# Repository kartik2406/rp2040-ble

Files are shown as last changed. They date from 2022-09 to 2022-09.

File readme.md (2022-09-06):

# RP2040 BLE

A PCB that uses RP2040 MCU and HM-BT4502 BLE passthrough module.
This enables the RP2040 to communicated with other devices using Bluetooth.
The bluetooth module is connected via UART(0)

## 3D
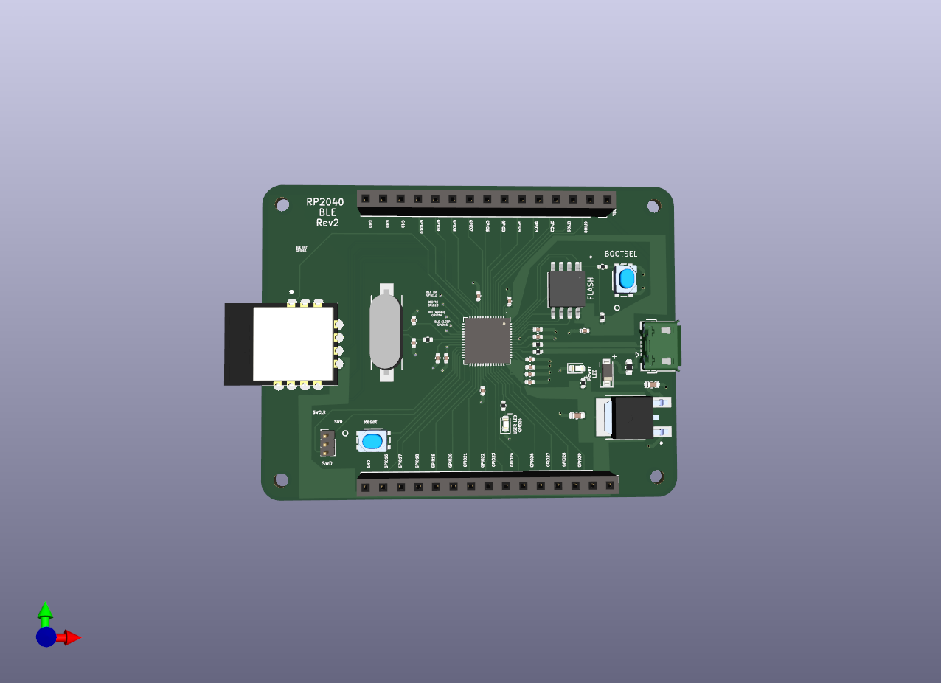
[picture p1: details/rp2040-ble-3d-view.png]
PCB 3D view


## PCB front layer
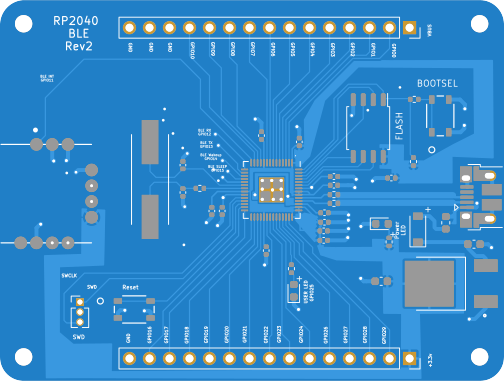
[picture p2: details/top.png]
PCB Front


## PCB back layer
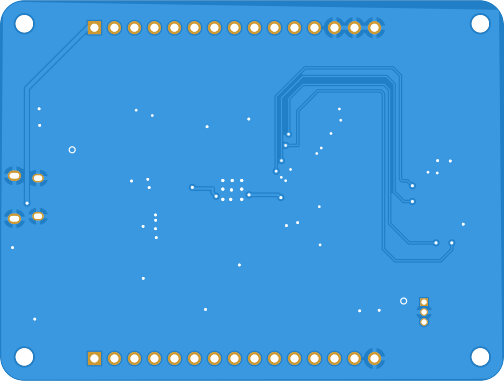
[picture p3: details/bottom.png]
PCB Back


## Generating board images
I used the gerber viewer on [PCBWay](https://www.pcbway.com/project/OnlineGerberViewer.html),
Downloaded the SVG renders from it, then converted the top and bottom SVGs to PNGs

## Helpful tutorials
- [The RP2040 hardware design guide, its in depth and cover things nicely](https://datasheets.raspberrypi.com/rp2040/hardware-design-with-rp2040.pdf)
- [An Intro to KiCad – Part 1: How PCBs Are Made](https://www.youtube.com/watch?v=vaCVh2SAZY4&list=PLEBQazB0HUyR24ckSZ5u05TZHV9khgA1O&ab_channel=Digi-Key)
- [Hardware Design with the RP2040: Custom PCB Based on the Raspberry Pi Pico](https://www.youtube.com/watch?v=kcwvuwetgEQ&ab_channel=Digi-Key)
- [Raspberry Pi RP2040 Hardware Design](https://www.youtube.com/watch?v=X00Cm5LMNQk&ab_channel=Phil%E2%80%99sLab)
- [KiCad STM32 + USB + Buck Converter PCB Design](https://www.youtube.com/watch?v=C7-8nUU6e3E&ab_channel=Phil%E2%80%99sLab)
- [KiCad 6 STM32 PCB Design Full Tutorial ](https://www.youtube.com/watch?v=aVUqaB0IMh4&ab_channel=Phil%E2%80%99sLab)
- [Designing a PCB for the RP2040 Microcontroller](https://www.teachmemicro.com/designing-a-pcb-for-the-rp2040-microcontroller/)
## Credits
- Most of the tutorial videos are from [Shawn Hymel](https://www.youtube.com/c/ShawnHymel), [Phil’s Lab](https://www.youtube.com/c/PhilS94).
They have amazing content do check them out.
- [Reddit PCB review thread](https://www.reddit.com/r/PrintedCircuitBoard/comments/wz8so7/pcb_review_rp2040_based_ble_board/),
thank you [Worldly-Protection-8](https://www.reddit.com/user/Worldly-Protection-8/), [DNosnibor](https://www.reddit.com/user/DNosnibor/) for the valuable review and feedback.

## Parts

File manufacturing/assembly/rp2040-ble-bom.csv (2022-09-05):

Source: | D:\electronic-schematics\rp2040-ble\rp2040-ble.kicad_sch
Date: | 04-09-2022 9.00.25 PM
Tool: | Eeschema (6.0.6)
Generator: | C:\Program Files\KiCad\6.0\bin\scripting\plugins/bom_csv_grouped_by_value_with_fp.py
Component Count: | 42
Ref | Qnty | Value | Cmp name | Footprint | Description | Vendor | Robu ID
C1, C2, C3, C4, C6, C7, C9, C11, C12, C14, | 10 | 100n | C_Small | Capacitor_SMD:C_0402_1005Metric | Unpolarized capacitor, small symbol | CL05B104KO5NNNC
C5, C8, | 2 | 1u | C_Small | Capacitor_SMD:C_0402_1005Metric | Unpolarized capacitor, small symbol | CL05A105KA5NQNC
C10, C13, | 2 | 27p | C_Small | Capacitor_SMD:C_0402_1005Metric | Unpolarized capacitor, small symbol | CL05C270JB5NNNC
C15, C16, | 2 | 10u | C_Small | Capacitor_SMD:C_0603_1608Metric | Unpolarized capacitor, small symbol | CL10A106KP8NNNC
D1, | 1 | BLUE | LED_Small | LED_SMD:LED_0603_1608Metric | Light emitting diode, small symbol | 150060BS75000
D2, | 1 | GREEN | LED_Small | LED_SMD:LED_0603_1608Metric | Light emitting diode, small symbol | 150060VS75000
D3, | 1 | B5819W | D_Schottky_Small | Diode_SMD:D_SOD-123 | Schottky diode, small symbol | B5819W
F1, | 1 | 100mA | Polyfuse_Small | Fuse:Fuse_0603_1608Metric | Resettable fuse, polymeric positive temperature coefficient, small symbol | 0603L004YR
J1, J2, | 2 | Conn_01x15 | Conn_01x15 | Connector_PinSocket_2.54mm:PinSocket_1x15_P2.54mm_Vertical | Generic connector, single row, 01x15, script generated (kicad-library-utils/schlib/autogen/connector/)
J3, | 1 | USB_B_Micro | USB_B_Micro | Connector_USB:USB_Micro-B_Amphenol_10103594-0001LF_Horizontal | USB Micro Type B connector | 10103594-0001LF
J4, | 1 | Conn_01x03 | Conn_01x03 | Connector_PinHeader_1.27mm:PinHeader_1x03_P1.27mm_Vertical | Generic connector, single row, 01x03, script generated (kicad-library-utils/schlib/autogen/connector/)
R1, R2, | 2 | 27.4 | R_Small | Resistor_SMD:R_0402_1005Metric | Resistor, small symbol | RMCF0402FT27R4
R4, R5, R6, R7, | 4 | 1k | R_Small | Resistor_SMD:R_0402_1005Metric | Resistor, small symbol | RC0402FR-071KL
R8, | 1 | DNF | R_Small | Resistor_SMD:R_0402_1005Metric | Resistor, small symbol
SW1, SW2, | 2 | PTS810_SJK_250_SMTR_LFS | PTS810_SJK_250_SMTR_LFS | PTS810:PTS810 SJK 250 SMTR LFS |  | PTS810 SJK 250 SMTR LFS
U1, | 1 | RP2040 | RP2040 | Package_DFN_QFN:QFN-56-1EP_7x7mm_P0.4mm_EP3.2x3.2mm | A microcontroller by Raspberry Pi | SC0914(7) | 997534
U2, | 1 | W25Q128JVS | W25Q128JVS | Package_SO:SOIC-8_5.23x5.23mm_P1.27mm | 128Mb Serial Flash Memory, Standard/Dual/Quad SPI, SOIC-8 | W25Q128JVSIQ
U3, | 1 | HM-BT4502 | HM-BT4502 | Custom:MODULE_HM-BT4502 |  | 113990814 | 1195286
U4, | 1 | NCP1117DT33G | NCP1117DT33G | NCP1117DT33G:VREG_NCP1117DT33G |  | NCP1117DT33G
Y1, | 1 | ABLS-12.000MHZ-B4-T | ABLS-12.000MHZ-B4-T | ABLS-12:XTAL_ABLS-12.000MHZ-B4-T |  | ABLS-12.000MHZ-B4-T

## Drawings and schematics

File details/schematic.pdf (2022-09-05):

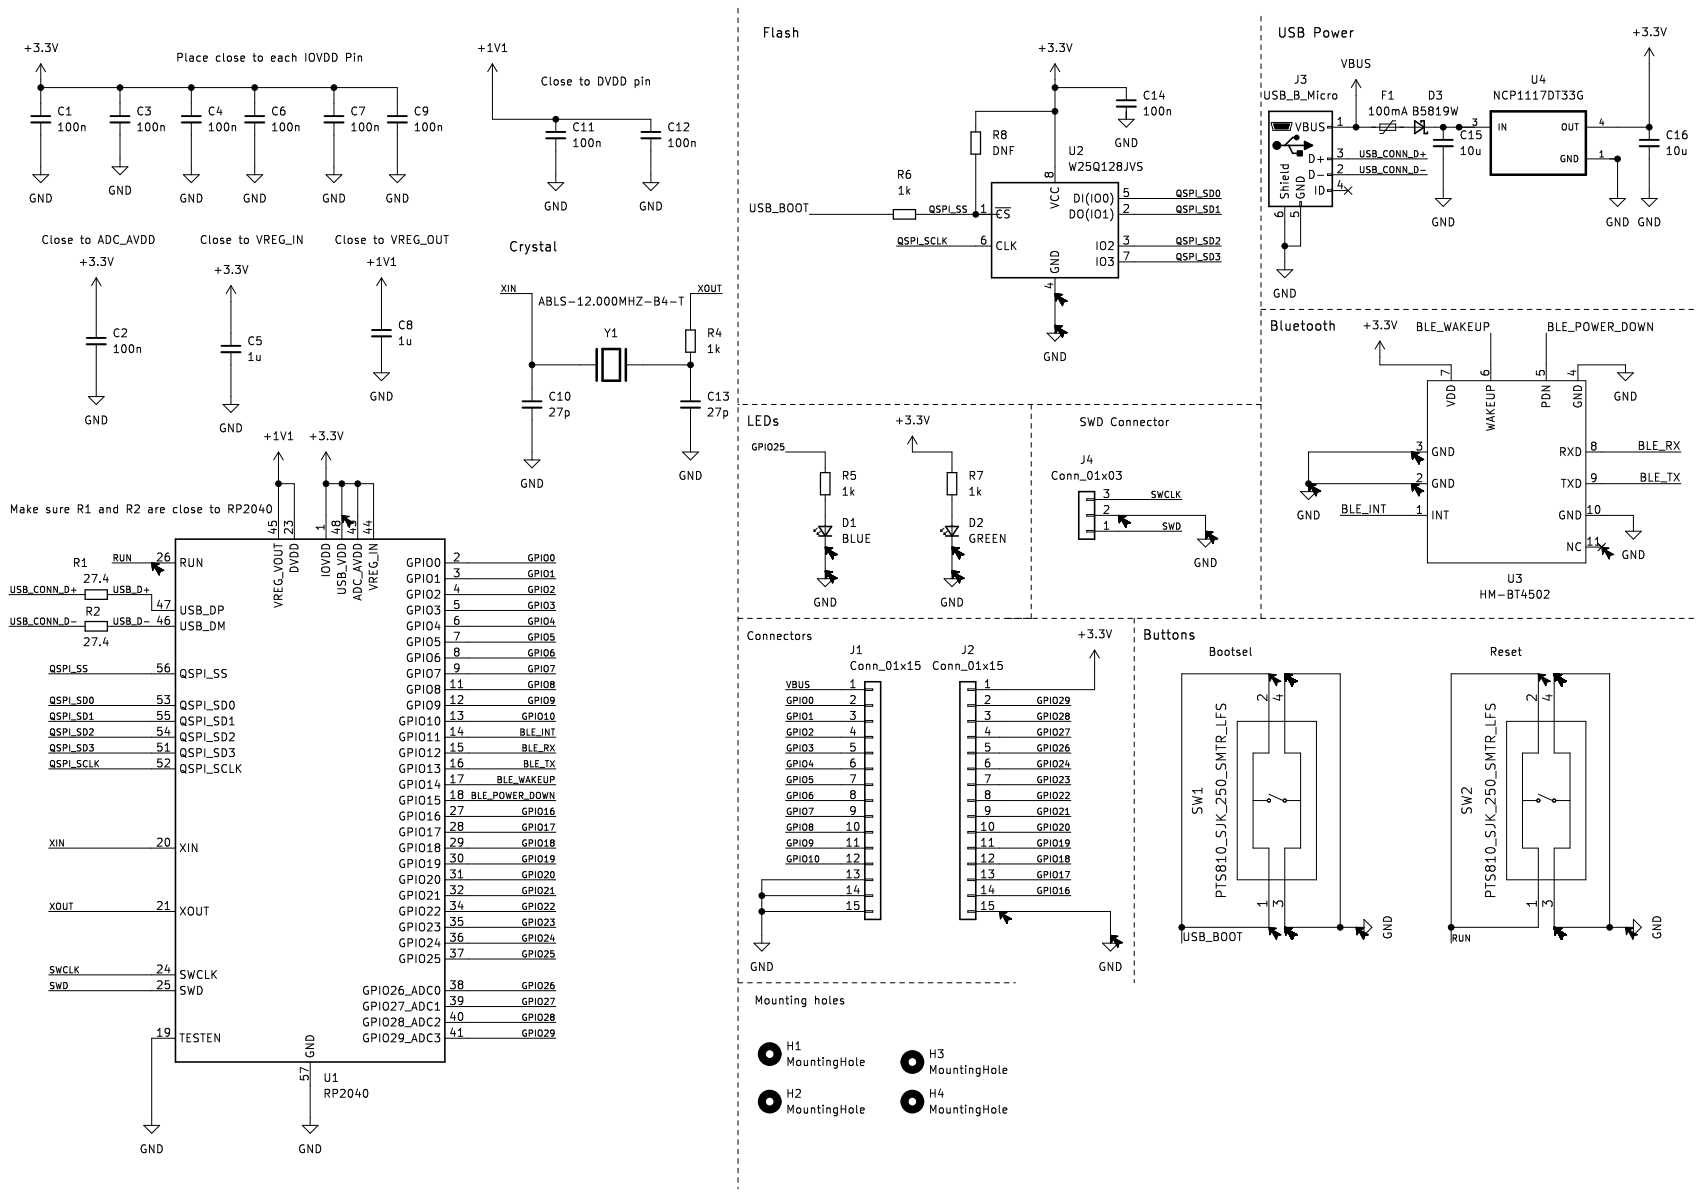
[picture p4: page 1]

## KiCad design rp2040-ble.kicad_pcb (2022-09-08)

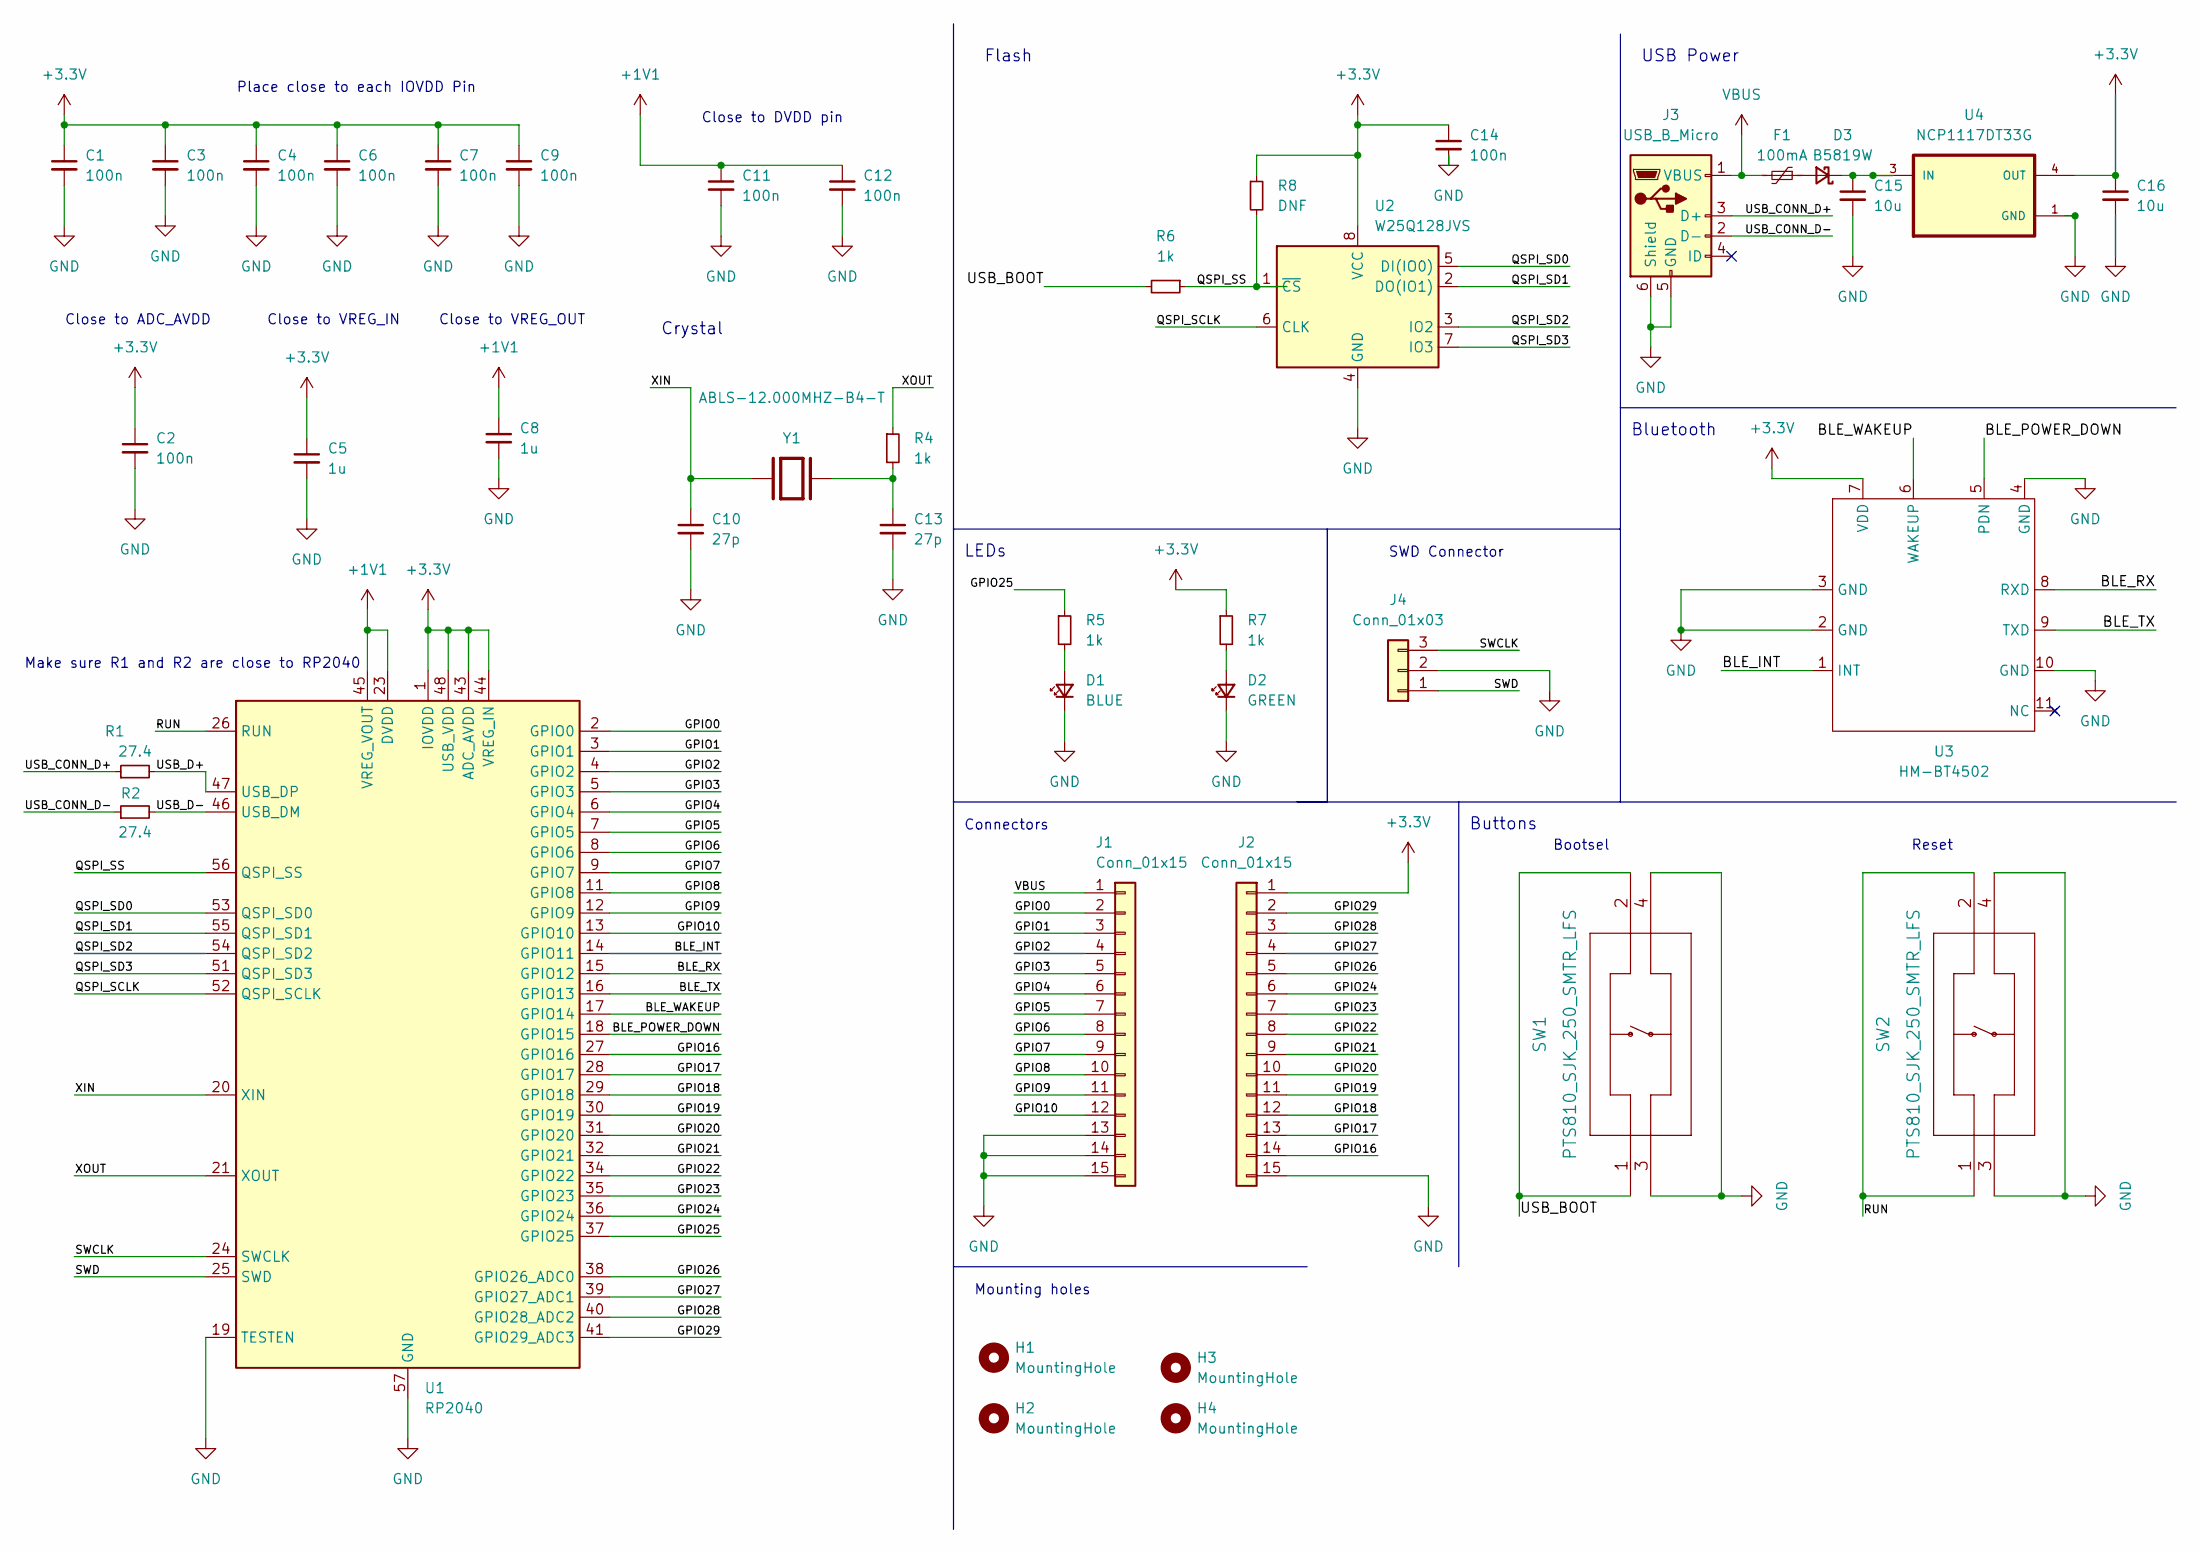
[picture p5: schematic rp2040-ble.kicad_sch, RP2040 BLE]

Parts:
C1, C2, C3, C4, C6, C7, C9, C11, C12, C14: 100n; C_0402_1005Metric
C5, C8: 1u; C_0402_1005Metric
C10, C13: 27p; C_0402_1005Metric
C15, C16: 10u; C_0603_1608Metric
D1: BLUE; LED_0603_1608Metric
D2: GREEN; LED_0603_1608Metric
D3: B5819W; D_SOD-123
F1: 100mA; Fuse_0603_1608Metric
H1, H2, H3, H4: MountingHole; MountingHole_2.2mm_M2
J1, J2: Conn_01x15; PinSocket_1x15_P2.54mm_Vertical
J3: USB_B_Micro; USB_Micro-B_Amphenol_10103594-0001LF_Horizontal
J4: Conn_01x03; PinHeader_1x03_P1.27mm_Vertical
R1, R2: 27.4; R_0402_1005Metric
R4, R5, R6, R7: 1k; R_0402_1005Metric
R8: DNF; R_0402_1005Metric
SW1, SW2: PTS810_SJK_250_SMTR_LFS; PTS810 SJK 250 SMTR LFS
U1: RP2040; QFN-56-1EP_7x7mm_P0.4mm_EP3.2x3.2mm
U2: W25Q128JVS; SOIC-8_5.23x5.23mm_P1.27mm
U3: HM-BT4502; MODULE_HM-BT4502
U4: NCP1117DT33G; VREG_NCP1117DT33G
Y1: ABLS-12.000MHZ-B4-T; XTAL_ABLS-12.000MHZ-B4-T; PARTREV 02.16.2021

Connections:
+1V1: C8.1, C11.1, C12.1, U1.23 (DVDD), U1.45 (VREG_VOUT), U1.50 (DVDD)
+3.3V: C1.1, C2.1, C3.1, C4.1, C5.1, C6.1, C7.1, C9.1, C14.1, C16.1, J2.1, R7.1, R8.1, U1.1 (IOVDD), U1.10 (IOVDD), U1.22 (IOVDD), U1.33 (IOVDD), U1.42 (IOVDD), U1.43 (ADC_AVDD), U1.44 (VREG_IN), U1.48 (USB_VDD), U1.49 (IOVDD), U2.8 (VCC), U3.7 (VDD), U4.4 (OUT)
/BLE_INT: U1.14 (GPIO11), U3.1 (INT)
/BLE_POWER_DOWN: U1.18 (GPIO15), U3.5 (PDN)
/BLE_RX: U1.15 (GPIO12), U3.8 (RXD)
/BLE_TX: U1.16 (GPIO13), U3.9 (TXD)
/BLE_WAKEUP: U1.17 (GPIO14), U3.6 (WAKEUP)
/GPIO0: J1.2, U1.2 (GPIO0)
/GPIO1: J1.3, U1.3 (GPIO1)
/GPIO2: J1.4, U1.4 (GPIO2)
/GPIO3: J1.5, U1.5 (GPIO3)
/GPIO4: J1.6, U1.6 (GPIO4)
/GPIO5: J1.7, U1.7 (GPIO5)
/GPIO6: J1.8, U1.8 (GPIO6)
/GPIO7: J1.9, U1.9 (GPIO7)
/GPIO8: J1.10, U1.11 (GPIO8)
/GPIO9: J1.11, U1.12 (GPIO9)
/GPIO10: J1.12, U1.13 (GPIO10)
/GPIO16: J2.14, U1.27 (GPIO16)
/GPIO17: J2.13, U1.28 (GPIO17)
/GPIO18: J2.12, U1.29 (GPIO18)
/GPIO19: J2.11, U1.30 (GPIO19)
/GPIO20: J2.10, U1.31 (GPIO20)
/GPIO21: J2.9, U1.32 (GPIO21)
/GPIO22: J2.8, U1.34 (GPIO22)
/GPIO23: J2.7, U1.35 (GPIO23)
/GPIO24: J2.6, U1.36 (GPIO24)
/GPIO25: R5.1, U1.37 (GPIO25)
/GPIO26: J2.5, U1.38 (GPIO26_ADC0)
/GPIO27: J2.4, U1.39 (GPIO27_ADC1)
/GPIO28: J2.3, U1.40 (GPIO28_ADC2)
/GPIO29: J2.2, U1.41 (GPIO29_ADC3)
/QSPI_SCLK: U1.52 (QSPI_SCLK), U2.6 (CLK)
/QSPI_SD0: U1.53 (QSPI_SD0), U2.5 (DI(IO0))
/QSPI_SD1: U1.55 (QSPI_SD1), U2.2 (DO(IO1))
/QSPI_SD2: U1.54 (QSPI_SD2), U2.3 (IO2)
/QSPI_SD3: U1.51 (QSPI_SD3), U2.7 (IO3)
/QSPI_SS: R6.1, R8.2, U1.56 (QSPI_SS), U2.1 (~CS)
/RUN: SW2.1, SW2.2, U1.26 (RUN)
/SWCLK: J4.3, U1.24 (SWCLK)
/SWD: J4.1, U1.25 (SWD)
/USB_BOOT: R6.2, SW1.1, SW1.2
/USB_CONN_D+: J3.3 (D+), R1.1
/USB_CONN_D-: J3.2 (D-), R2.1
/USB_D+: R1.2, U1.47 (USB_DP)
/USB_D-: R2.2, U1.46 (USB_DM)
/XIN: C10.1, U1.20 (XIN), Y1.1
/XOUT: R4.1, U1.21 (XOUT)
GND: C1.2, C2.2, C3.2, C4.2, C5.2, C6.2, C7.2, C8.2, C9.2, C10.2, C11.2, C12.2, C13.2, C14.2, C15.2, C16.2, D1.1 (K), D2.1 (K), J1.13, J1.14, J1.15, J2.15, J3.5 (GND), J3.6 (Shield), J4.2, SW1.3, SW1.4, SW2.3, SW2.4, U1.19 (TESTEN), U1.57 (GND), U2.4 (GND), U3.2 (GND), U3.3 (GND), U3.4 (GND), U3.10 (GND), U4.1 (GND)
unnamed: C13.1, R4.2, Y1.2
unnamed: C15.1, D3.1 (K), U4.3 (IN)
unnamed: D1.2 (A), R5.2
unnamed: D2.2 (A), R7.2
unnamed: D3.2 (A), F1.1
VBUS: F1.2, J1.1, J3.1 (VBUS)

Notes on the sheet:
LEDs
Buttons
Close to VREG_OUT
SWD Connector
Bootsel
Close to ADC_AVDD
Close to DVDD pin
Crystal
Bluetooth
Reset
Mounting holes
Flash
Close to VREG_IN
Make sure R1 and R2 are close to RP2040
Place close to each IOVDD Pin
USB Power
Connectors

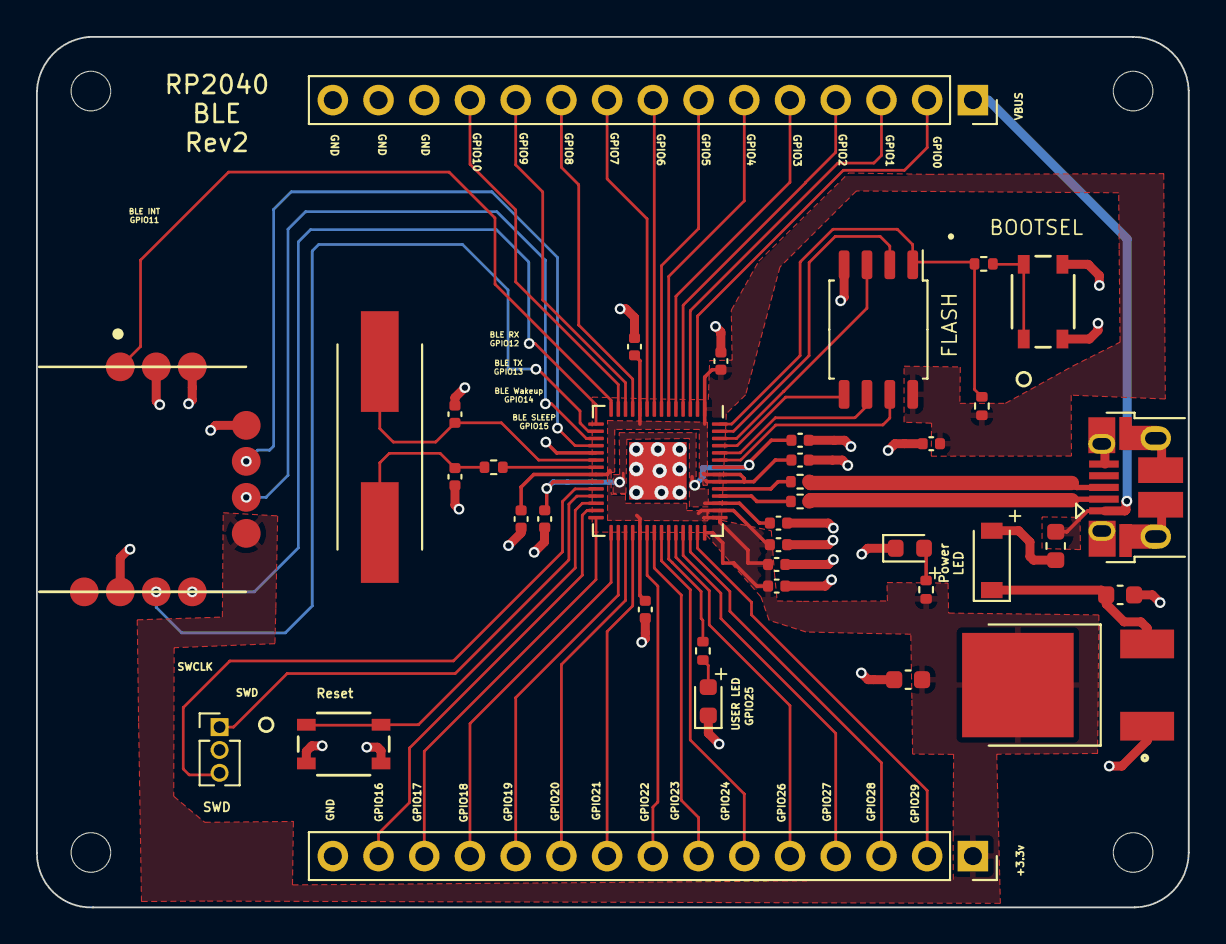
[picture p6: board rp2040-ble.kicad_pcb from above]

Board: 2 copper layers, 64.0 x 48.4 mm, 42 parts (0 on the bottom side), 55 nets.

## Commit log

2022-08-23 WIP Routing
    [rp2040-ble - Copy.kicad_pcb, rp2040-ble.kicad_pcb, rp2040-ble.kicad_sch]
2022-08-24 PCB roouting
    [rp2040-ble.kicad_pcb, rp2040-ble.kicad_sch]
2022-08-25 Updated routing, addedd 3d models for parts
    [rp2040-ble.kicad_pcb, rp2040-ble.kicad_sch]
2022-08-27 Add gerbers, fix pcb issues
    [rp2040-ble-B_Cu.gbr, rp2040-ble-B_Mask.gbr, rp2040-ble-B_Paste.gbr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]
2022-08-27 Add Images for review
    [rp2040-ble.kicad_pcb]
2022-08-27 Update readme with images
    [rp2040-ble-bom.xlsx]
2022-09-05 Incorporate review feedback
    [rp2040-ble - Copy.kicad_pcb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]
2022-09-06 Generate board screenshots
    [rp2040-ble-B_Cu.gbr, rp2040-ble-B_Mask.gbr, rp2040-ble-B_Paste.gbr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]
2022-09-06 Update the readme
    [rp2040-ble.kicad_pcb]
2022-09-08 Add rev and missing liscense
    [rp2040-ble.kicad_pcb, rp2040-ble.kicad_sch]

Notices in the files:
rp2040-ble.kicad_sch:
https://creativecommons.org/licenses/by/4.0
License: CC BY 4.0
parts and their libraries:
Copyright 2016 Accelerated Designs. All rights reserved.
